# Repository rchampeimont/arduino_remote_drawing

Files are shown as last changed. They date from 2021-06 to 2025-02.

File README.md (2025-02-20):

# arduino_remote_drawing
An Arduino-based system to synchronize drawings on two remote touchscreens through a Redis server.

Project demo on YouTube: https://www.youtube.com/watch?v=fHJE1c8BRzo&list=PLyapHjQ6m2qxmw1AHN88vVNvwXfSJUXou

Here is what the finished project looks like, with the two stations in their 3D-printed cases:

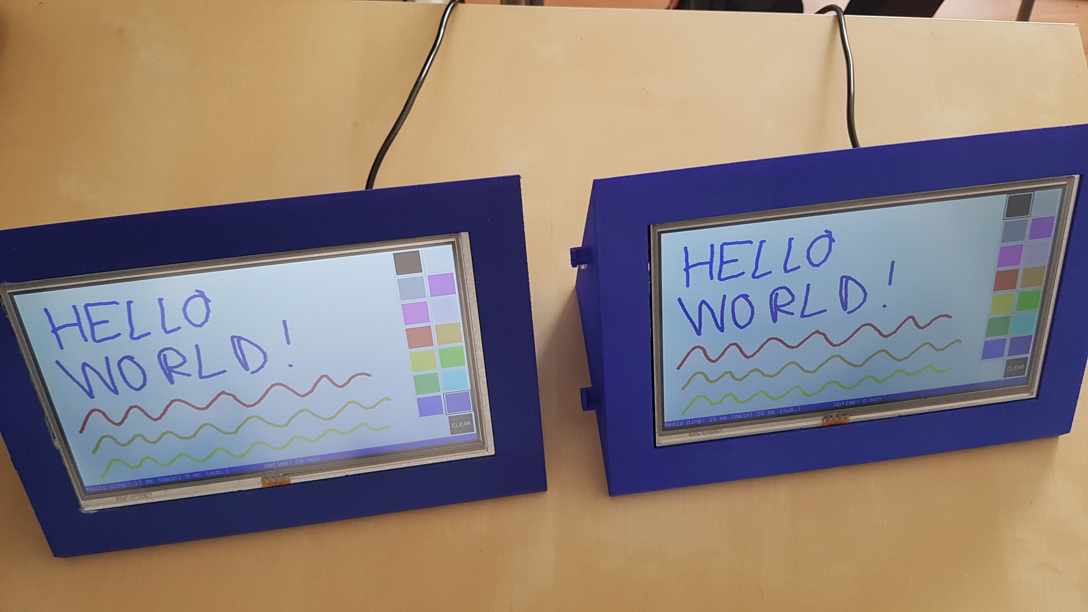
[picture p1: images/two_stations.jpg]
Photo of what the project looks like


Here is an example of drawing a more complex image:

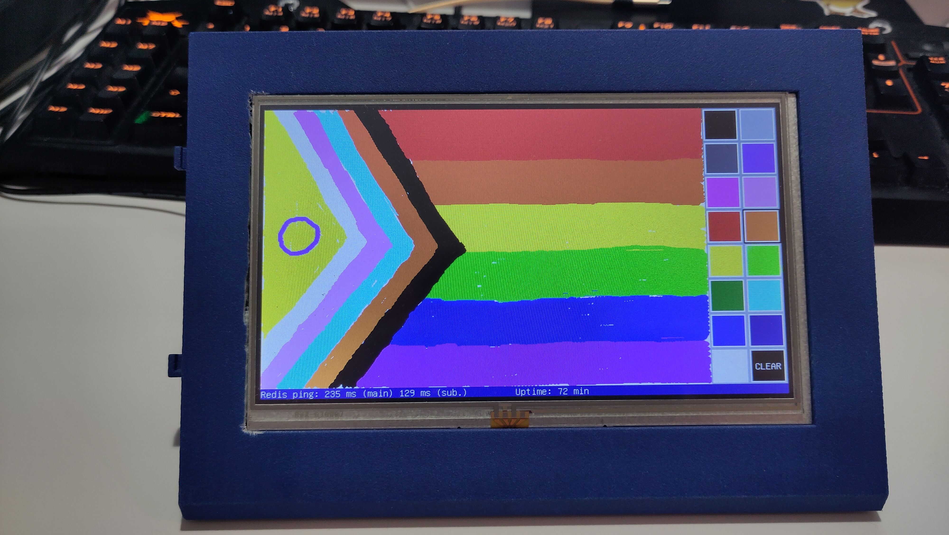
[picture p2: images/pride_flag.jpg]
Pridge flag drawn on device


And here is what's inside:

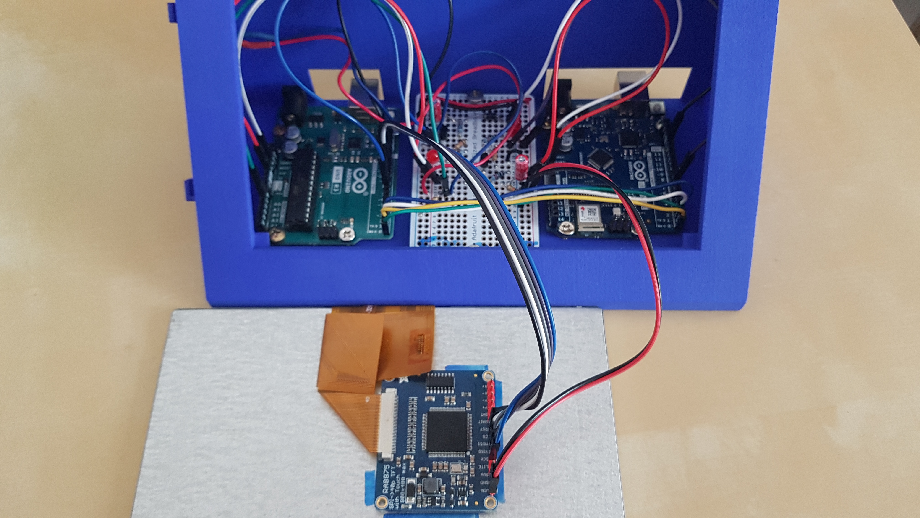
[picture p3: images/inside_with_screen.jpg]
Inside a station


Here is the general overview of the whole system:

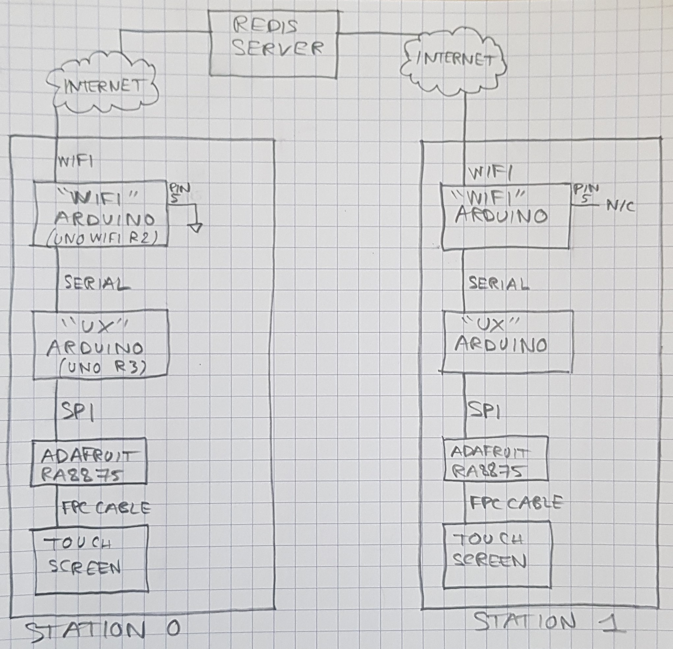
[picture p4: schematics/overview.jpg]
General diagram


Each station is made of the following hardware (so you need all this twice):
* Arduino Uno Wifi Rev2
* Arduino Uno Rev3
* Adafruit RA8875 Driver Board for 40-pin TFT Touch Displays - 800x480 Max https://www.adafruit.com/product/1590
* Adafruit 7.0" 40-pin TFT Display - 800x480 with Touchscreen https://www.adafruit.com/product/2354
* A phototransistor: I used the one in the Arduino starter kit (https://www.arduino.cc/documents/datasheets/HW5P-1.pdf) but you can probably use another one. This is used to adapt the brightness of the screen according to ambiant light, but this is not stricly necessary (replace the phototransistor with a wire if you don't want this feature).
* Some standard components: resistors, diodes, capacitors and NPN transistors. See schematic below for details.

As you can see in the diagram above, you also need a Redis server that can be accessed by the two stations. Here we use Redis to store the drawing and to create a pub/sub channel so that each station gets changes in real-time (a few seconds). So you need to have a Linux server running around the clock for the project to work. But if you already have one, adding a Redis server is very simple (you just need to set port number and password) and will require very little resources (Redis uses only a few megabytes of RAM). Learn more about Redis here: https://redis.io/

Here is the complete schematic for one station:

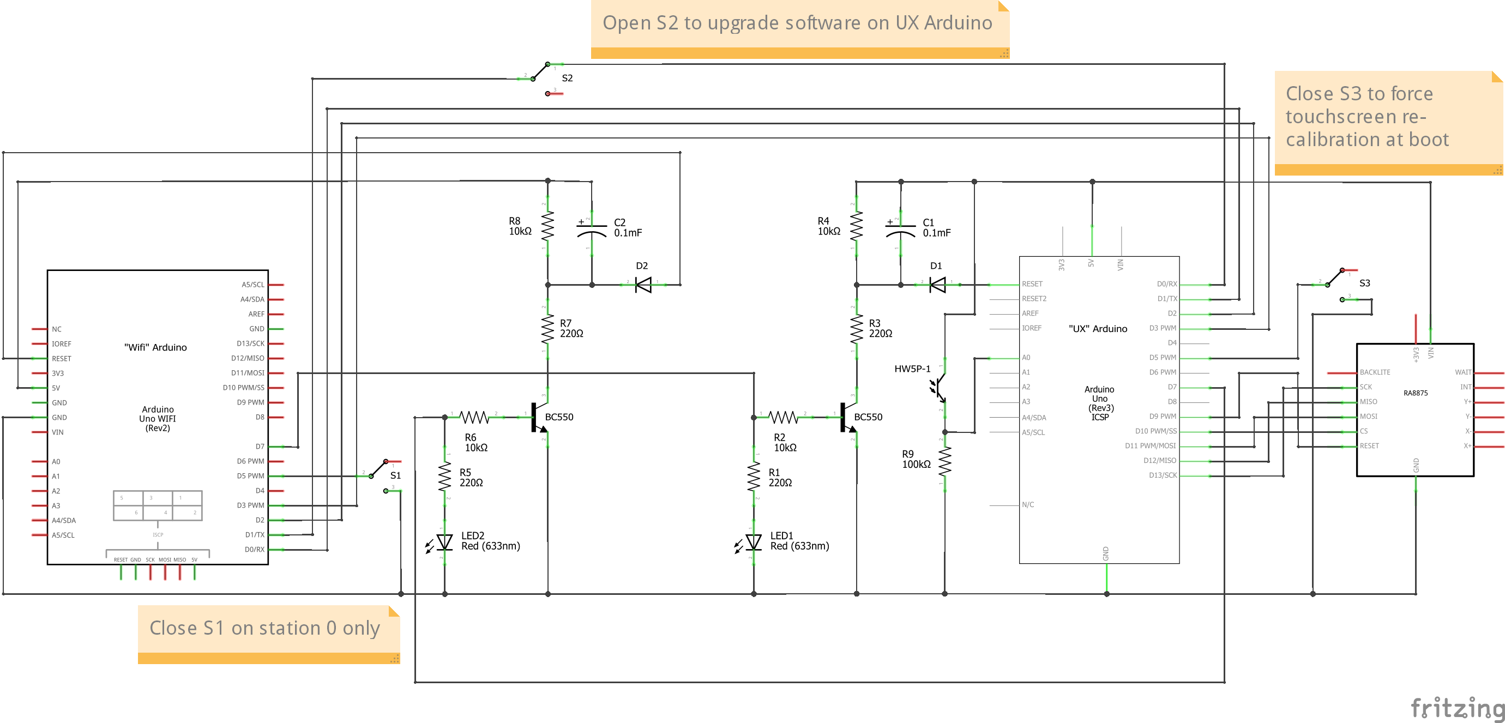
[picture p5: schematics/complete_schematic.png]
Complete schematic


## "Wifi" Arduino (for Arduino Uno Wifi Rev2)
To compile the code for the "Wifi" Arduino (remote_drawing_wifi directory), you need to rename the secrets.txt file and you put your own secrets in it (Wifi password and Redis host and password).

## "UX" Arduino (for Arduino Uno Rev3)
The code for the UX Arduino (remote_drawing_ux directory) does not need any secrets and can be compiled and uploaded to an Arduino Uno directly.

The first time you run the program, it is going to ask you to calibrate the touch screen. It then stores the calibration data in EEPROM to skip calibration on future restarts. If you want to force recalibration, you can tie pin 5 to ground and restart the Arduino.

## Powering it
To power the system, you can of course connect a USB cable to each Arduino, but it's a bit annoying to have two cables and adapters. So in my case, I connected a 9V adapter to the jack input on the Arduino Uno Wifi R2, then I connected the 5V of both Arduinos together, which means that all voltage conversion from 9V to 5V is done by the Arduino Uno Wifi R2, which does that more efficiently and heats less (it uses an MPM3610 chip) than the Arduino Uno (it uses NCP1117 chip).

Here are some benchmarks showing that this is indeed the most efficient configuration:
* 9V to VIN of Arduino Uno Wifi R2 and 5V pins tied together: 0.17 A
* 9V to VIN of Arduino Uno R3 and 5V pins tied together: 0.25 A
* 9V to both VINs tied together (5V are not tied): 0.24 A

## More details on the "reset circuit"
As you can see in the schematic above, this circuit is present twice:

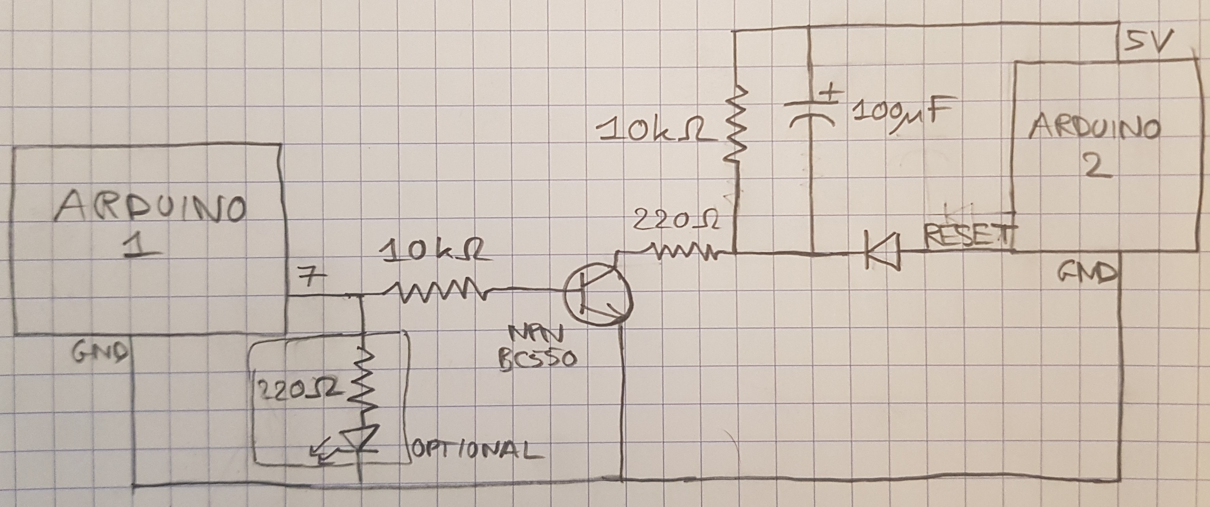
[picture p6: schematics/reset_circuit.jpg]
Reset circuit

It allows each Arduino (Arduino 1 above) to reset the other Arduino (Arduino 2 above). The optional part with an LED is if you want to see when a reset is triggered (LED will be on for 1/2 second).

This is useful for instance for crash detection and automatic reboot: Each Arduino pings the other every second. This allows each Arduino to detect when the other one is crashed, and reboot it.

Why use this complex circuit and not simply connect an output pin of one Arduino to the RESET pin of the other? If we did that, we would have the following issues:
* When Arduino 1 above is resetting, it would temporarily pull pow the RESET pin of Arduino A2 low, triggering a reset on the other side. Since they are both connected to each other like this, this would result in a deadlock situation where every RESET pin is pulled low and no one "releases" it. To avoid that, we invert the logic: Arduino 1 pulls Pin 7 high to make Arduino 2 RESET pin go low. This inversion is accomplished with the NPN transistor.
* When an Arduino is not connected to power or is being connected, there are transitory artefactul voltage variations on the pins (here pin 7), which can trigger a reboot. To get rid of these artefactual reboots, we charge a capacitor, and the RESET is triggered when the capacitor is sufficiently charged.
* A last issue is that pulling high the RESET pin (ie. when we don't want to trigger a reset from code) prevents resets from the computer via USB or the reset button, which is really annoying for development. The diode prevents this issue by making our circuit able to pull low but not high the reset pin.

Here is what the circuit behavior look like when a reset on one Arduino is triggered by the other:
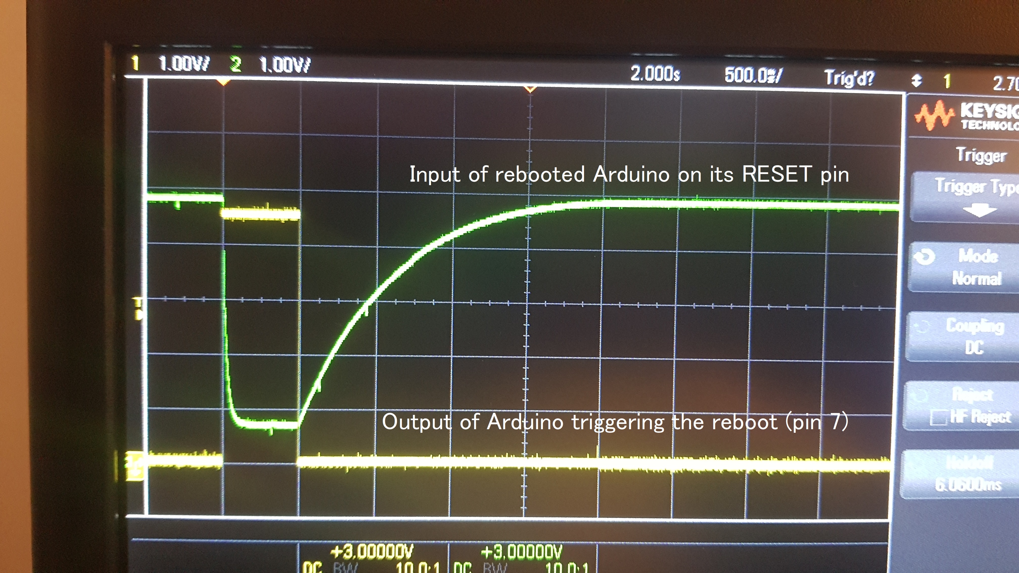
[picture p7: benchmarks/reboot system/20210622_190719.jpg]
Pin 7 and RESET pin measures on an oscilloscope


## If your Wifi password has changed
Here is a [documentation](docs/change_wifi_password.md) to follow if you need to change your Wifi password.

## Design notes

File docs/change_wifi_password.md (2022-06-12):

# How to change my Wifi password?
If your Wifi password has changed, the remote drawer will not work any more and will display an error saying it failed to connect to Wifi
(FATAL: Connection to Wifi network "[you Wifi name]" failed).

To upload the new Wifi password, first disconnect your remote drawer from the power supply,
and connect the USB port which is on the Wifi Arduino to the computer you used to upload it initially.

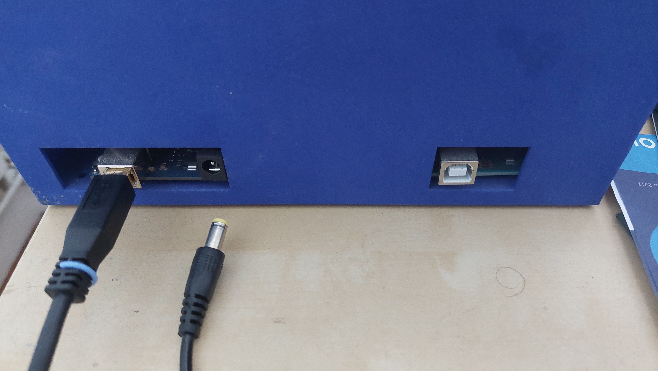
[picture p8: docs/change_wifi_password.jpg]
How to connect the Remote Drawer to the computer to change the Wifi password


Open the Arduino application and open the `secrets.h` file which you created during the initial setup.

If you don't have it any more, you need to do again the initial setup as explained in
[the general README](../README.md#wifi-arduino-for-arduino-uno-wifi-rev2)
with both the Wifi credentials and the Redis server credentials.

If you still have the `secrets.h` file, you just need to change the `WIFI_PASSWORD` variable
(and `WIFI_NAME` if your Wifi does not have the same name any more).

Set the port and Arduino hardware correctly:
* Tools -> Board -> Arduino megaAVR Board -> Arduino Uno Wifi Rev2
* Tools -> Registers emulation -> None (ATMEGA4809)
* Port -> Select the port which shown "Arduino Uno Wifi Rev2" in parenthesis after the port name

Click "upload". The remote drawer should restart and then work properly.

You can then disconnect the USB cable from the remote drawer and connect back the power supply.

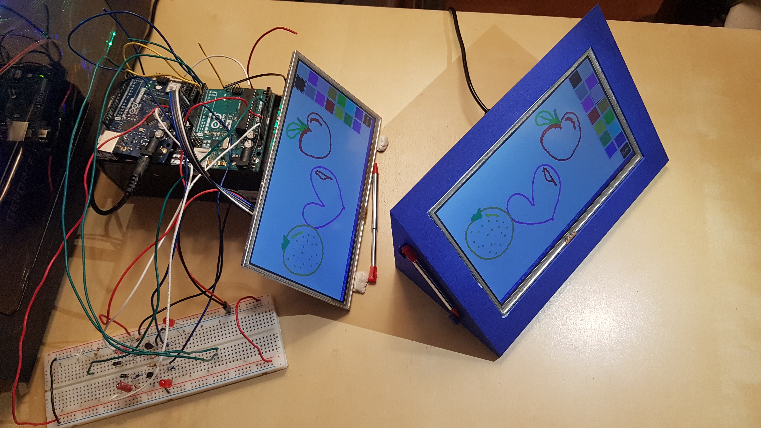
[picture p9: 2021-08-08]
images/overview_both.jpg

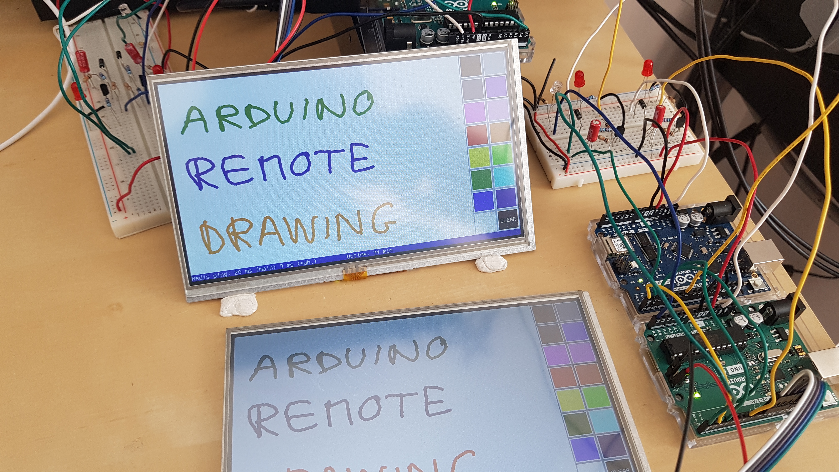
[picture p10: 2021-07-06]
images/overview.jpg

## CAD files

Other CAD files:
3D_model/teledrawer.skp

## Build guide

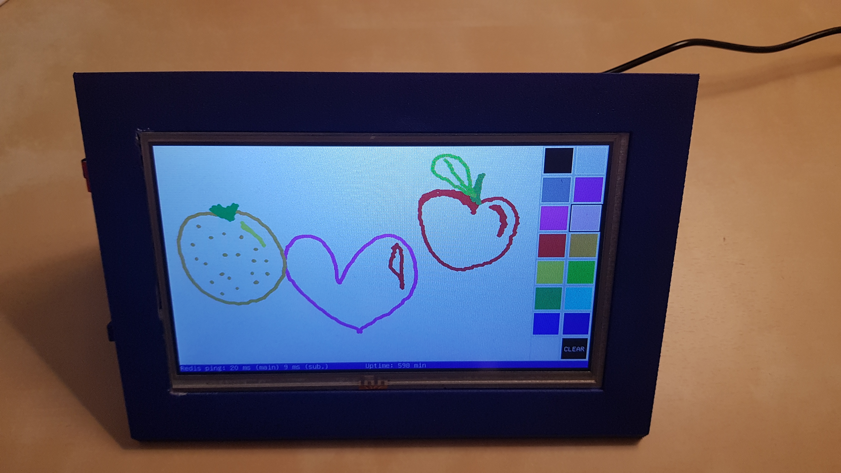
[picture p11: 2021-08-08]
images/assembled.jpg

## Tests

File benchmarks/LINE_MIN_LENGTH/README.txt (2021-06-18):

I tested a few different settings of MIN_LINE_LENGTH in remote_drawing_ux.
This optimization is not used any more, as I have replaced it by a constant sampling period instead of a minimum line length.
Constant sampling period gave better results and gave a predictable bandwidth so was better.
It was better for the user because it allows to draw slowly to be more precise, while min line length forces imprecision.

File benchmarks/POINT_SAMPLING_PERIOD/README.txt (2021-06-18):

I tested a few different settings of POINT_SAMPLING_PERIOD in remote_drawing_ux

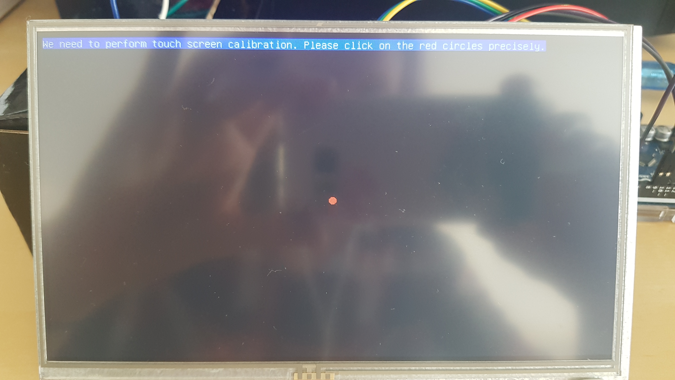
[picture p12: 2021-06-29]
images/calibration.jpg

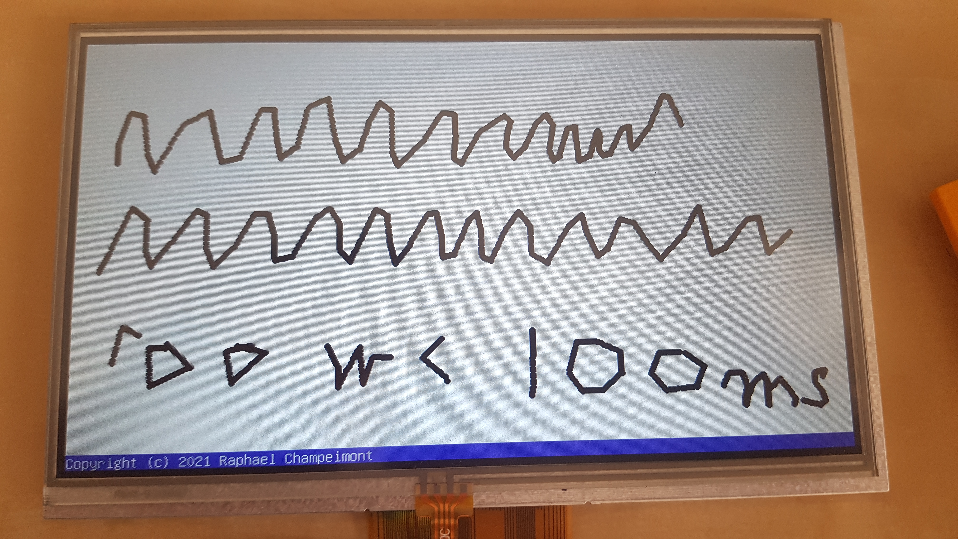
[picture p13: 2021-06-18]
benchmarks/POINT_SAMPLING_PERIOD/100ms.jpg

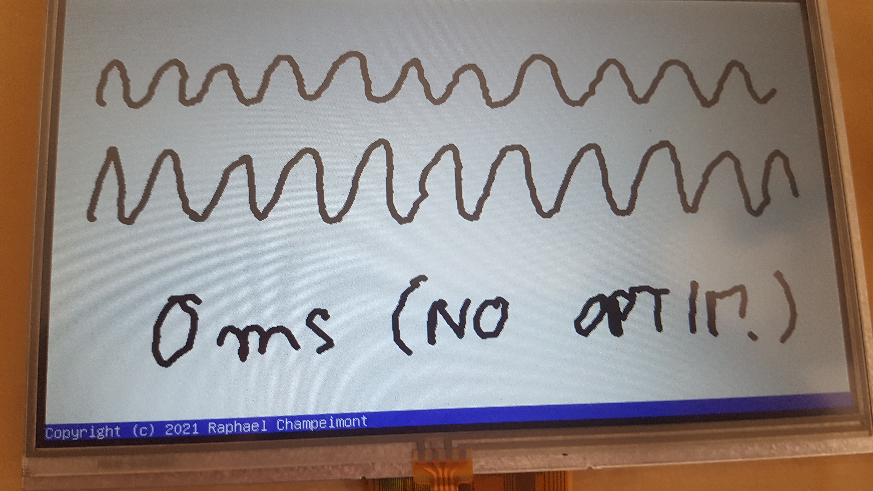
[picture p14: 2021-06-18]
benchmarks/POINT_SAMPLING_PERIOD/0ms.jpg

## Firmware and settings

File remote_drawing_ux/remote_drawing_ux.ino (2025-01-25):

// Program designed for Arduino Uno Rev3

#include "Adafruit_RA8875.h"
#include "system.h"
#include "calibrate.h"
#include "serial_com.h"
#include "backlight.h"
#include "bars.h"

// Period for telling the other Arduino that we are alive
#define TELL_ALIVE_EVERY 1000

// TFT Display resolution
#define DISPLAY_WIDTH 800
#define DISPLAY_HEIGHT 480

#define LINE_WIDTH 3

// How many filled circles to draw to draw a big line
#define LINE_STEPS 10

// Record a line point every
#define POINT_SAMPLING_PERIOD 20 // ms

// Colors
#define NUMBER_OF_COLORS 15
const uint16_t COLORS[NUMBER_OF_COLORS] {
  RA8875_BLACK,
  0xBDD7, // light grey
  0x630C, // dark grey
  0x981F, // violet
  RA8875_MAGENTA,
  0xFC3E, // pink
  RA8875_RED,
  0xFB60, // orange
  RA8875_YELLOW,
  RA8875_GREEN,
  0x0443, // dark green
  RA8875_CYAN,
  RA8875_BLUE,
  0b0000000000001111, // dark blue
  RA8875_WHITE
};

// Consider the pen is realsed after this delay
#define RELEASE_DELAY 50 // ms

Adafruit_RA8875 tft = Adafruit_RA8875(RA8875_CS_PIN, RA8875_RESET_PIN);

void setup() {
  pinMode(PIN_TO_OTHER_ARDUINO_RESET_CIRCUIT, OUTPUT);
  pinMode(WIFI_ARDUINO_INTERRUPT_PIN, OUTPUT);
  pinMode(DEBUG_LOOP_RUN_TIME_PIN, OUTPUT);
  pinMode(DEBUG_CRASH_PIN, OUTPUT);
  pinMode(DEBUG_SPECIFIC_PIN, OUTPUT);
  pinMode(READY_TO_DRAW_PIN, INPUT);

  tft.begin(RA8875_800x480);

  tft.displayOn(true);
  tft.GPIOX(true);      // Enable TFT - display enable tied to GPIOX

  initBacklight();

  // Setup touch screen
  tft.touchEnable(true);
  setupCalibration();

  tft.fillScreen(RA8875_WHITE);

  printStatus("Copyright (c) 2021 River Champeimont - UX version " VERSION);

  initToolbar();
  renderToolbar();

  // Reset the "Wifi" Arduino so that it resends us the drawing
  resetOther();
}

void drawBigLine(Line line) {
  int DX = line.x1 - line.x0;
  int DY = line.y1 - line.y0;
  for (int i = 0; i < LINE_STEPS; i++) {
    tft.fillCircle(
      line.x0 + i / (float) LINE_STEPS * DX,
      line.y0 + i / (float) LINE_STEPS * DY,
      LINE_WIDTH,
      COLORS[line.color]);
  }
}


void clearDisplayedDrawing() {
  tft.fillRect(0, 0, DISPLAY_WIDTH - TOOLBAR_WIDTH, DISPLAY_HEIGHT - STATUS_BAR_SIZE, RA8875_WHITE);
}


void handleReceive() {
  char statusMessage[MAX_STATUS_MESSAGE_LENGTH + 1];

  while (Serial.available() >= (int) sizeof(ReceivedPacket)) {
    ReceivedPacket packet;
    if (serialReceivePacket(&packet, statusMessage)) {
      switch (packet.opcode) {
        case SERIAL_COM_LINE_OPCODE:
          drawBigLine(packet.data.line);
          // While loading the initial drawing, the Wifi Arduino does not send
          // "alive" packets yet, and sends only lines, so we must consider
          // them as proof that the other Arduino is alive.
          aliveReceived();
          break;
        case SERIAL_COM_MSG_OPCODE:
          printStatus(statusMessage);
          // Initial Redis connection can take long,
          // so consider status messages as proof of alive.
          aliveReceived();
          break;
        case SERIAL_COM_CLEAR_OPCODE:
          clearDisplayedDrawing();
          break;
        case SERIAL_COM_ALIVE_OPCODE:
          aliveReceived();
          break;
        default:
          error("Wifi->UX Arduino invalid opcode: 0x%x", packet.opcode);
      }
    }
  }
}



// Compute an approximate distance between (x1,y1) and (x2,y2)
int approxDistance(int x1, int y1, int x2, int y2) {
  // Use L1 norm because it's fast to compute and does not overflow 16-bit integers
  return abs(x1 - x2) + abs(y1 - y2);
}

// Average the coordinates of two points
void averagePoints(int x0, int y0, int x1, int y1, int *x, int *y) {
  *x = x0 + (x1 - x0) / 2;
  *y = y0 + (y1 - y0) / 2;
}

// We sometimes get random incorrect values from the touch screen.
// To handle that, we perform the following operation for every 3 successive ponits:
// We take the two that are nearest to each other,
// and average their corrdinates to make the final coordinates.
void extractPoint(int x1, int y1, int x2, int y2, int x3, int y3, int *x, int *y) {
  int d12 = approxDistance(x1, y1, x2, y2);
  int d23 = approxDistance(x2, y2, x3, y3);
  int d31 = approxDistance(x3, y3, x1, y1);
  if (d12 < d23) {
    if (d31 < d12) {
      // Points 1 and 3 are the nearest
      averagePoints(x1, y1, x3, y3, x, y);
    } else {
      // Points 1 and 2 are the nearest
      averagePoints(x1, y1, x2, y2, x, y);
    }
  } else {
    if (d31 < d23) {
      // Points 1 and 3 are the nearest
      averagePoints(x1, y1, x3, y3, x, y);
    } else {
      // Points 2 and 3 are the nearest
      averagePoints(x2, y2, x3, y3, x, y);
    }
  }
}

void handleTouch() {
  static int lastTouchX = -1;
  static int lastTouchY = -1;
  static int beforeLastTouchX = -1;
  static int beforeLastTouchY = -1;
  static int lastLineX = -1;
  static int lastLineY = -1;
  static unsigned long lastLinePointTime = 0;
  static bool buttonPressed = false;

  // We use 0 as meaning "not released"
  static unsigned long penReleaseTime = 1;

  uint16_t rawX, rawY;
  int highPrecisionX = -1, highPrecisionY = -1, lowPrecisionX = -1, lowPrecisionY = -1;

  // Wifi Arduino is not ready to receive data, so don't allow user to draw
  if (digitalRead(READY_TO_DRAW_PIN) == LOW) return;

  if (tft.touched()) {
    penReleaseTime = 0;
    tft.touchRead(&rawX, &rawY);

    // Put brightness at 100% to avoid PWM-related interferences
    adjustBacklightForTouch();

    // Translate touch screen coordinates to display coordinates
    if (translateTouchCoords(rawX, rawY, &lowPrecisionX, &lowPrecisionY) == 0
        && lowPrecisionX >= 0
        && lowPrecisionY >= 0
        && lowPrecisionX < DISPLAY_WIDTH
        && lowPrecisionY < DISPLAY_HEIGHT) {

      if (beforeLastTouchX >= 0 && lastTouchX >= 0) {
        // Compute high-precision coordinates of clicked point by averaging successive coordinates
        extractPoint(beforeLastTouchX, beforeLastTouchY, lastTouchX, lastTouchY, lowPrecisionX, lowPrecisionY, &highPrecisionX, &highPrecisionY);

        unsigned long now = millis();
        if (highPrecisionX >= DRAWABLE_WIDTH || highPrecisionY >= DRAWABLE_HEIGHT) {
          // We are oustide the drawable area, so try to detect a click on a button
          if (lastLineX == -1 && !buttonPressed && handleToolbarClick(highPrecisionX, highPrecisionY)) {
            // This flag is to avoid repeating click on button until user releases pen.
            buttonPressed = true;
          }
        } else if (lastLineX >= 0 && ! buttonPressed) {
          // We are continuing a line.
          // Limit the number of line points generated per second, to optimize bandwidth
          if (now >= lastLinePointTime + POINT_SAMPLING_PERIOD) {
            Line line;
            line.x0 = lastLineX;
            line.y0 = lastLineY;
            line.x1 = highPrecisionX;
            line.y1 = highPrecisionY;
            line.color = selectedColor;

            drawBigLine(line);
            serialTransmitLine(line);

            lastLineX = highPrecisionX;
            lastLineY = highPrecisionY;
            lastLinePointTime = now;
          }
        } else if (! buttonPressed) {
          // This is the first point of the line, so let's draw a single point
          // because the user might want to draw a single point and release the pen.
          Line line;
          line.x0 = highPrecisionX;
          line.y0 = highPrecisionY;
          line.x1 = highPrecisionX;
          line.y1 = highPrecisionY;
          line.color = selectedColor;

          drawBigLine(line);
          serialTransmitLine(line);

          lastLineX = highPrecisionX;
          lastLineY = highPrecisionY;
          lastLinePointTime = now;
        }
      }

      beforeLastTouchX = lastTouchX;
      beforeLastTouchY = lastTouchY;
      lastTouchX = lowPrecisionX;
      lastTouchY = lowPrecisionY;
    }
  } else {
    if (penReleaseTime == 0) {
      // This is the first loop where the pen is released, so record release time.
      penReleaseTime = millis();
    } else if (millis() - penReleaseTime > RELEASE_DELAY) {
      // Pen has been released for long enough, so consider the pen really released.
      buttonPressed = false;
      beforeLastTouchX = -1;
      beforeLastTouchY = -1;
      lastTouchX = -1;
      lastTouchY = -1;
      lastLineX = -1;
      lastLineY = -1;
    }
  }
}


void loop() {
  static unsigned long lastAliveSentTime = millis();

  digitalWrite(DEBUG_LOOP_RUN_TIME_PIN, HIGH);
  handleTouch();

  digitalWrite(DEBUG_LOOP_RUN_TIME_PIN, LOW);
  handleReceive();

  unsigned long now = millis();
  if (now >= lastAliveSentTime + TELL_ALIVE_EVERY) {
    // Tell the other Arduino we are still alive
    serialTransmitAlive();

    // Check that the other Arduino is still alive
    checkAlive();

    lastAliveSentTime = now;
  }

  updateBacklightIfNecesary();
}

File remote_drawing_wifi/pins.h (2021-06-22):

#ifndef PINS_H
#define PINS_H

// Pin tied to its own reset pin ("Wifi" Arduino)
#define RESET_PIN_SELF 6

// Pin tied to the other Arduino reset pin ("UX" Arduino)
#define RESET_PIN_OTHER 7

// This pin must be pulled LOW on one of the two Wifi Arduinos
#define CLIENT_ID_PIN 5

// Where to detect interrupts coming from the UX Arduino
#define WIFI_ARDUINO_INTERRUPT_PIN 2

#define DEBUG_PIN 12

extern byte myClientId;

// Reboot the entire system (both Arduinos). This function never returns.
void reboot();

#endif

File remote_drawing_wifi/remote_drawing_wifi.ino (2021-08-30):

// Program designed for Arduino Uno Wifi Rev2.
// ATMEGA328 registers emulation is not needed.

#include <WiFiNINA.h>

#include "wifi.h"
#include "serial_com.h"
#include "secrets.h"
#include "redis_client.h"
#include "system.h"

// Reboot every day to avoid issues linked with millis() overflow
// and for safety if we get stuck in a bad state.
#define REBOOT_EVERY_MS 86400000

// Period for telling the other Arduino that we are alive
#define TELL_ALIVE_EVERY 1000

void setup() {
  pinMode(LED_BUILTIN, OUTPUT);
  digitalWrite(LED_BUILTIN, HIGH);

  pinMode(DEBUG_ISR_TIME_PIN, OUTPUT);
  pinMode(DEBUG_CRASH_PIN, OUTPUT);
  pinMode(PIN_TO_OTHER_ARDUINO_RESET_CIRCUIT, OUTPUT);
  pinMode(WIFI_ARDUINO_INTERRUPT_PIN, INPUT);
  pinMode(READY_TO_DRAW_PIN, OUTPUT);

  // Serial connection to computer, used for debug only
  Serial.begin(9600);
  while (!Serial) {
    ; // wait for serial port to connect. Needed for native USB port only
  }

  Serial.println("");
  Serial.println("====================================================");
  Serial.println("Arduino restarted.");
  Serial.println("Setting up...");

  Serial1.begin(115200, SERIAL_8E1);

  initClientId();

  // Init serial connection to the other Arduino
  serialInit();

  initWifi();

  connectToRedisServer();

  downloadInitialData();

  // Empty serial read buffer
  Serial1.end();
  Serial1.begin(115200, SERIAL_8E1);

  // Start receiving data from UX Arduino
  attachInterrupt(digitalPinToInterrupt(WIFI_ARDUINO_INTERRUPT_PIN), handleSerialReceive, FALLING);

  // Tell UX Arduino that it can now send data
  digitalWrite(READY_TO_DRAW_PIN, HIGH);

  Serial.println("Setup finished.");
  Serial.println("====================================================");
  digitalWrite(LED_BUILTIN, LOW);
}

// This function is an Interrupt Service Routine (ISR)
void handleSerialReceive() {
  digitalWrite(DEBUG_ISR_TIME_PIN, HIGH);

  // We cannot wait for data in an ISR,
  // so we need to make sure the packet is already completely received
  while (Serial1.available() >= (int) sizeof(ReceivedPacket)) {
    ReceivedPacket packet;
    if (serialReceivePacket(&packet) == 0) {
      fatalError("UX Arduino failed to read serial packet");
      return;
    }
    switch (packet.opcode) {
      case SERIAL_COM_LINE_OPCODE:
        redisAddLineToSendBuffer(packet.data.line);
        break;
      case SERIAL_COM_CLEAR_OPCODE:
        redisPlanClearDrawing();
        break;
      case SERIAL_COM_ALIVE_OPCODE:
        aliveReceived();
        break;
      default:
        fatalError("UX->Wifi Arduino invalid opcode: 0x%x", packet.opcode);
    }
  }

  digitalWrite(DEBUG_ISR_TIME_PIN, LOW);
}

void handleRedisReceive() {
  RedisMessage redisMessage;
  if (redisReceiveMessage(&redisMessage)) {
    Serial.write("Redis message received: From client ");
    Serial.print(redisMessage.fromClientId);
    Serial.print(" - Opcode: ");
    Serial.print(redisMessage.opcode);
    if (redisMessage.opcode == REDIS_LINE_OPCODE) {
      Serial.write(" - Interval: ");
      Serial.print(redisMessage.data.lineInterval.newLinesStartIndex);
      Serial.write(" to ");
      Serial.print(redisMessage.data.lineInterval.newLinesStopIndex);
    }
    Serial.println("");

    // Download lines only if they come from the other client,
    // otherwise it means that the lines were drawn by our own user
    // so they are already displayed on our screen.
    if (redisMessage.fromClientId != myClientId) {
      switch (redisMessage.opcode) {
        case REDIS_LINE_OPCODE:
          getLinesFromRedisAndDrawThem(
            redisDownloadLinesBegin(
              redisMessage.data.lineInterval.newLinesStartIndex,
              redisMessage.data.lineInterval.newLinesStopIndex));
          break;
        case REDIS_CLEAR_OPCODE:
          sendStatusMessage("Your friend cleared the drawing.");
          serialTransmitClear();
          break;
        default:
          fatalError("Redis message contains invalid opcode: 0x%x", redisMessage.opcode);
      }
    }
  }
}

void getLinesFromRedisAndDrawThem(long count) {
  Line line;

  for (long i = 0; i < count; i++) {
    // Receive line from Redis
    redisDownloadLine(&line);
    // Send line to UX Arduino to render it on screen
    serialTransmitLine(line);
  }
}

void downloadInitialData() {
  long count;

  sendStatusMessage("Downloading drawing from server...");
  count = redisDownloadLinesBegin(0, -1);

  sendStatusMessageFormat("Downloading drawing from server (%ld lines). Please wait...", count);
  getLinesFromRedisAndDrawThem(count);
  sendStatusMessageFormat("Downloaded %ld lines. You can now draw!", count);
}

void loop() {
  // Last Alive packet sent
  static unsigned long lastAliveSentTime = millis();

  handleRedisReceive();
  runRedisPeriodicTasks();

  while (millis() > REBOOT_EVERY_MS) {
    sendStatusMessage("It's time for the periodic reboot! Please wait a minute...");
    // The other Arduino is then going to reset us at boot
    resetOther();
    // Retry after 60 sec if reset failed
    delay(60000);
  }

  unsigned long now = millis();
  if (now >= lastAliveSentTime + TELL_ALIVE_EVERY) {
    // Tell the UX Arduino we are alive
    serialTransmitAlive();

    // Check if the UX Arduino is alive
    checkAlive();

    char s[100];
    snprintf(s, sizeof(s), "I am alive. Last alive received %d seconds ago.\n", noResponseFromUxArduinoSeconds);
    Serial.write(s);

    lastAliveSentTime = now;
  }
}

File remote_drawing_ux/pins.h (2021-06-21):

#ifndef PINS_H
#define PINS_H

// Adafruit RA8875 connections:
// Connect SCLK to ICSP SCK
// Connect MISO to ICSP MISO
// Connect MOSI to ICSP MOSI
#define RA8875_CS_PIN 10
#define RA8875_RESET_PIN 9

// Tie this pin to ground to force recalibration at start time
#define FORCE_CALIBRATE_PIN 5

// Pin which is connected to the pin declared as WIFI_ARDUINO_INTERRUPT_PIN on the Wifi Arduino
#define WIFI_ARDUINO_INTERRUPT_PIN 2

#endif

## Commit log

2021-06-17 remove warning LED
2021-06-18 Replace "min line length" optimization by "constant sampling period"
    [remote_drawing_ux.ino]
2021-06-18 fix drawing download error
    [remote_drawing_wifi.ino]
2021-06-21 optimize by avoiding memcpy
    [redis_client.ino]
2021-06-21 reboot on serial loss of sync
    [remote_drawing_wifi.ino]
2021-06-21 Rewrite Wifi Arduino code to use Line type
2021-06-21 et voila la couleur
2021-06-21 some half-working version with interrupts
2021-06-21 try to fix some things
    [redis_client.ino, remote_drawing_wifi.ino]
2021-06-21 fix error in buffer size
    [redis_client.ino]
2021-06-21 allow easier debug with internal LED
2021-06-22 use debug pin
2021-06-22 Fix the random freeze bug
    [remote_drawing_wifi.ino, serial_com.ino]
2021-06-22 version with fixed packet size
    [remote_drawing_ux.ino, remote_drawing_wifi.ino, serial_com.ino]
2021-06-22 start implementing crash detection system
    [redis_client.ino, remote_drawing_ux.ino, remote_drawing_wifi.ino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]
2021-06-22 work in progress auto reboot
    [remote_drawing_ux.ino, system.h, system.ino]
2021-06-23 add "Uno R3" to schematic
2021-06-23 set relevant reboot times
    [remote_drawing_wifi.ino, system.ino]
2021-06-23 fix some part of the alive system
    [remote_drawing_ux.ino, remote_drawing_wifi.ino]
2021-06-24 towards serial bug resolution
    [remote_drawing_wifi.ino, system.h, system.ino]
2021-06-24 solve UX->Wifi transmission error by using smaller packets
    [remote_drawing_ux.ino, remote_drawing_wifi.ino, serial_com.ino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]
2021-06-24 Fix Wifi->UX serial errot
    [remote_drawing_ux.ino, remote_drawing_wifi.ino, serial_com.ino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]
2021-06-24 upload schematic made with Fritzing
    [sketch.fzz]
2021-06-24 add system overview
    [sketch.fzz]
2021-06-24 Move RA8875 connections to general schematic
    [sketch.fzz]
2021-06-24 update schematic
    [sketch.fzz]
2021-06-25 Set TFT screen backlight according to photosensor
    [sketch.fzz]
2021-06-28 Prevent drawing when not ready
    [sketch.fzz]
2021-06-28 Tell UX we are not ready in case of crash
    [system.ino]
2021-06-28 Avoid global variables in Wifi code
    [redis_client.ino, remote_drawing_wifi.ino, wifi.ino]
2021-06-28 Avoid global variables when possible
    [remote_drawing_ux.ino]
2021-06-28 Avoid crash when clicking CLEAR while friend is drawing
    [remote_drawing_ux.ino]
2021-07-03 calibration : allow for more time to click on the dots
2021-07-05 Fix interference between PWM and touch data
    [backlight.ino, remote_drawing_ux.ino]
2021-07-06 Update teledrawer.skp
    Add pen holder on the side of the teledrawer
    [teledrawer.skp]
2021-08-05 Use A0 for photsensor pin
    Closes https://github.com/raphaelchampeimont/arduino_remote_drawing/issues/2
    [system.h]
2021-08-06 Make screen brighter
    Closes https://github.com/raphaelchampeimont/arduino_remote_drawing/issues/3
    [backlight.ino, system.h]
2021-08-07 Allow screen brightness to reach 0/255
    Closes https://github.com/raphaelchampeimont/arduino_remote_drawing/issues/5
    [backlight.ino, system.h]
2021-08-07 Larger screen hole and different borders
    We're adding 1mm on each screen side (left and right) and we are changing the way the border to hold the screen are made.
    [teledrawer.skp]
2021-08-07 Bigger sensor hole and touch pen holder
    [teledrawer.skp]
2021-08-07 Add photo of assembled project
2021-08-08 Update arduinos holes spacing
    closes https://github.com/raphaelchampeimont/arduino_remote_drawing/issues/1
    [teledrawer.skp]
2021-08-12 add switch to allow for software upgrades
    [sketch.fzz]
2021-08-12 Update circuit to use A0 for photosensor
    In https://github.com/raphaelchampeimont/arduino_remote_drawing/commit/f7f62988627c0466afa7df19aac407bff37ac869 I had forgotten to update the circuit schematic
    [sketch.fzz]
2021-08-30 Allow loading an initial drawing of more than 32768 lines (#8)
    * change version number
    * switch initial drawing loading to 32 bit line count
    * Revert "change version number"
    This reverts commit 0693bd8ae636d85eac4fec4a0dd7aaf6ad37a61f.
    * update version number
    [redis_client.ino, remote_drawing_wifi.ino, system.h]
2021-09-04 Fix real-time bug when drawing lines after index 32768 (#9)
    * use 32-bit integers for line array indices in Redis messages
    * update UX code version number
    * other fixes necessary for 32 bit indices
    [redis_client.ino, system.h]
